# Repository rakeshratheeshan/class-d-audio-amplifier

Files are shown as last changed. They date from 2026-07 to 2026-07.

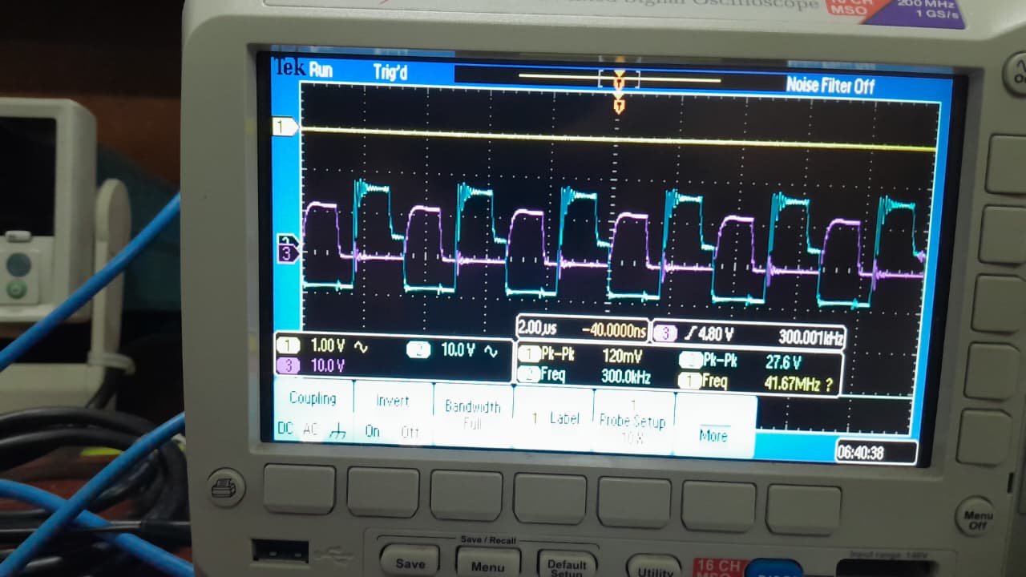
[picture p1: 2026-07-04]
Breadboard_impementation_and_Observation/Hi_Lo_gate.jpeg

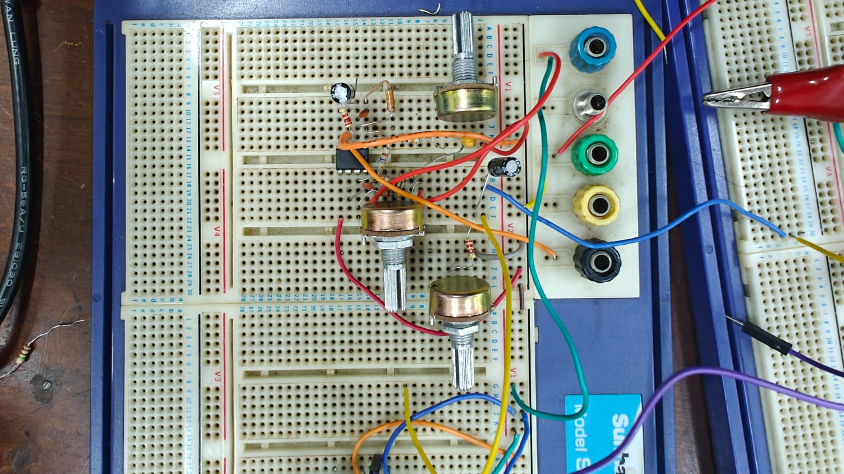
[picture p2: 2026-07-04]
Breadboard_impementation_and_Observation/pre_amp.jpeg

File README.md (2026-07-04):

# Class D Audio Amplifier

> EN 2111 — Electronic Circuit Design | University of Moratuwa  
> Department of Electronic and Telecommunication Engineering  
> Batch 23 — Group 14

A fully designed, simulated, and breadboard-implemented Class-D audio amplifier featuring a pre-amplifier with active Baxandall tone control, high-frequency PWM generation, a half-bridge MOSFET output stage with bootstrap gate driver, and a 4th-order Butterworth LC low-pass output filter.

---

## Team

| Name | Index | Task |
|---|---|---|
| De Mel D. J. | 230121D | MOSFET Gate Driver Design |
| Rahman M. F. A. | 230507R | PWM Generation Design |
| Rahul B. | 230508V | Pre-Amplifier Design |
| Ratheeshan A. R. | 230539P | Low-Pass Filter Design |

---

## System Architecture

```
Audio In → Pre-Amp → PWM Generator → Gate Driver → Half-Bridge → LC Filter → Speaker
(NE5532)   (AD8065 + LM311D)  (IR2104)     (IRF530 x2)  (4th-order Butterworth)
```

---

## Repository Structure

```
class-d-audio-amplifier/
├── report/                  # Final submitted report (PDF)
├── simulation/
│   ├── preamp/              # LTspice files — Pre-amplifier & tone control (Rahul)
│   ├── pwm/                 # LTspice files — Triangular wave gen & comparator (Abdul Rahman)
│   ├── gate-driver/         # LTspice files — IR2104 half-bridge driver (Deelaka)
│   └── filter/              # LTspice files — 4th-order LC Butterworth filter (Rakesh)
├── pcb/
│   ├── schematic/           # Altium Designer schematic files (.SchDoc, .PrjPcb)
│   └── layout/              # PCB layout files + Gerbers
└── docs/
    └── references/          # Datasheets and application notes
```

---

## Subsystem Summaries

### 1. Pre-Amplifier (`simulation/preamp/`)
- Built around the **NE5532** dual op-amp (5 nV/√Hz noise, 10 MHz BW)
- Inverting gain stage: **Av = −15 (≈ 23.5 dB)**, AC-coupled at 7.23 Hz lower cutoff
- Active **Baxandall tone control** with bass (±12 dB shelf below 200 Hz) and treble adjustment
- Volume control potentiometer for modulation index matching
- Simulated THD: **0.243%** at 500 Hz, 750 mV peak input

### 2. PWM Generation (`simulation/pwm/`)
- **Triangular wave generator**: AD8065 relaxation oscillator + inverting integrator
  - f ≈ 354 kHz (R = 3.9 kΩ, C = 330 pF, β = 0.5)
  - Integrator: Ri = 33 kΩ, Ci = 47 pF, 100 kΩ DC feedback resistor
- **Comparator**: LM311D (replaced LM393 for faster switching at 350 kHz)
- PWM duty cycle: `D(t) = 0.5 + V_audio(t) / (2 × V_tri_pk)`
- Final switching frequency reduced to **150 kHz** for IR2104 compatibility

### 3. Gate Driver (`simulation/gate-driver/`)
- **IR2104** half-bridge gate driver (final iteration)
  - Integrated dead-time generation (520 ns fixed)
  - Internal PWM inversion for complementary HS/LS outputs
  - Bootstrap capacitor: **100 nF** (Cboot > 10 × Cg = 1.8 nF)
  - VDD bypass capacitor: **1 µF** (CVDD > 10 × Cboot)
  - Bootstrap diode: **1N5819** Schottky
- MOSFETs: **IRF530** (selected over IRFZ44N for lower Qg = 26 nC and Ciss = 670 pF at 300 kHz)
- Required gate drive: Isource = 313 mA (within 83 ns, 5% of half-period)

### 4. Output Filter (`simulation/filter/`)
- **4th-order passive LC Butterworth low-pass filter** (LC ladder topology)
- Cutoff frequency: **20 kHz**, −40 dB/decade rolloff
- Designed for RS/RL mismatch (RS = 0.5 Ω, RL = 8 Ω → RL/RS ≈ 16)
- Component values: **L1 = 100 µH, C2 = 1.56 µF, L3 = 68 µH, C4 = 330 nF**
- Zobel network (future improvement): R = 5.6 Ω, C = 100 µF for variable speaker load compensation

---

## Key Design Decisions

| Decision | Chosen | Reason |
|---|---|---|
| Triangular wave IC | AD8065 (over NE555) | NE555 has DC offset and non-linear (exponential) waveform |
| Comparator | LM311D (over LM393) | Faster switching, cleaner transitions at 350 kHz |
| Gate driver | IR2104 (over LTC4444) | Integrated dead-time, simpler implementation; cost/time tradeoff |
| MOSFET | IRF530 (over IRFZ44N) | Lower Qg and Ciss → less switching loss at high frequency |
| Filter order | 4th-order (over 2nd-order) | Steeper rolloff needed after reducing fsw to 150 kHz |
| Filter type | Passive LC (over RC/active) | Zero dissipation, handles full output current, best ripple rejection |

---

## How to Contribute (For Group Members)

1. **Fork** this repository to your own GitHub account
2. **Clone** your fork locally:
   ```bash
   git clone https://github.com/<your-username>/class-d-audio-amplifier.git
   ```
3. Add the upstream remote:
   ```bash
   git remote add upstream https://github.com/230539P/class-d-audio-amplifier.git
   ```
4. Work inside **your assigned subfolder** only (see table above)
5. Push to your fork and open a **Pull Request** to `230539P/class-d-audio-amplifier`

To pull in updates from the main repo:
```bash
git fetch upstream
git merge upstream/main
```

---

## Tools Used

- **LTspice** — Circuit simulation
- **Altium Designer** — PCB schematic and layout
- **LaTeX (XeLaTeX)** — Report generation
- **Tektronix TBS1000C** — Oscilloscope measurements

---

## References

1. Texas Instruments — NE5532 Datasheet
2. Texas Instruments — LM311 Datasheet
3. Analog Devices — AD8065 Datasheet
4. Infineon — IRF530N Datasheet
5. Infineon — IR2104 Datasheet
6. Analog Devices — AN-1070: Class D Audio Amplifier Basics
7. Texas Instruments — Class-D Audio Amplifier Design Basics (SLAA701A)
8. Chris Bowick — *RF Circuit Design*, Reed Elsevier, 1982

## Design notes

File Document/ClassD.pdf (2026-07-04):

## University of Moratuwa

### Department of Electronic and Telecommunication Engineering

Faculty of Engineering

# Class D Audio Amplifier

### Design, Simulation and Practical Implementation

### Module: EN 2111 - Electronic Circuit Design

Batch: 23 | - | Group: 14

### Group Members

Name | | Index Number
De Mel D. J. | | 230121D
Rahman M. F. A. 230507R
Rahul B. | | pakaya
Ratheeshan A. R. 230539P

### June 26, 2026

# Contents

1 Introduction | 1
2 Theoretical Background | 2
3 Conclusion | 22
Datasheets and References | 23

i

# Introduction

## 1.1 Background and Motivation

Class-D amplifiers are widely used in modern audio systems because of their high efficiency. Unlike conventional linear amplifiers, they amplify audio by converting it into a high-frequency Pulse Width Modulated (PWM) signal, allowing the output MOSFETs

to operate as switches. This greatly reduces power loss while maintaining good audio quality. The aim of this project was to design, simulate, and implement a Class-D audio amplifier using commonly available components. Several design iterations were carried out to improve the PWM generation, gate driving, and output filtering stages before achieving the final design.

## 1.2 Objectives

The objectives of this project are to:

- Design and implement a complete Class-D audio amplifier.
- Generate PWM using a high-frequency triangular carrier and comparator.
- Design the MOSFET gate driver and output stage.
- Recover the amplified audio signal using an LC low-pass filter.
- Verify the design through simulation and practical testing.

## 1.3 Scope of the Report

This report covers the design, simulation, implementation, and testing of the Class-D audio amplifier, including the pre-amplifier, PWM generator, gate driver, output stage, LC filter, and PCB design.

## 1.4 Report Organisation

Chapter 2 presents the design and theory of each subsystem, while the remaining chapters cover simulation, implementation, testing, PCB design, results, challenges, and the final conclusions.

# Theoretical Background

## 2.1 Pre-Amplifier

### 2.1.1 Purpose and Role in the Signal Chain

The pre-amplifier stage serves as the front-end interface between audio sources such as smartphones, media players or DACs and the PWM stage of the Class-D Amplifier. The standard line-level audio equipment delivers audio signals ranging from 200 millivolts to 1 volts. The comparator LM311D requires an audio signal which should closely match the amplitude of the triangular wave to create a good PWM with high modulation index. For this purpose a pre-amplifier is needed. By maximizing the modulation index, the SNR increases and the voltage utilization factor of the output power rails also increases.

Beyond this, The pre-amplifier stage fullfills these roles:

- Impedance Buffering: Presenting a high input impedance to the incoming source

to eliminate signal loading, ensuring flat frequency transmission from the playback device.

- DC Isolation and Biasing: Utilizing an AC-coupling network to strip away any

residual DC offsets from the input source, ensuring that the audio signal centers precisely around the analog ground (0 V) of the split-supply system.

### 2.1.2 Design Considerations and Circuit Analysis

The complete pre-amplifier is designed around the NE5532 dual operational amplifier which has 5 nV/

√
Hz noise density and 10 MHz small-signal bandwidth which makes it perfect for our application.

### 1. Input Gain Stage

The first stage (U1) is configured as an inverting amplifier.The mid-band voltage gain (Av1):

Av1 = −

R2
R1

= −

33 kΩ
2.2 kΩ = −15 (≈ 23.5 dB) | (2.1)

The lower −3 dB cut-off frequency (fL1) of this initial block:

fL1 =

1
2πR1C1

=

1
2π × 2.2 kΩ × 10 µF
≈ 7.23 Hz | (2.2)

CHAPTER 2. THEORETICAL BACKGROUND | EN 2111 — Class D Amplifier

This pole is placed below the nominal 20 Hz audible threshold to avoid phase shifts in the bass range. Noise suppression is managed by the feedback capacitor C2 in parallel with R2 forming a low-pass filter with a corner frequency (fH1):

fH1 =

1
2πR2C2

=

1
2π × 33 kΩ × 47 pF
≈ 102.6 kHz | (2.3)

### 2. Active Baxandall Tone Control Stage

The output of U1 feeds into an active Baxandall tone control network built around the second operational amplifier stage (U3).

- Bass Control Loop: Resistors R3, R6, and capacitor C3 (47 nF) function together

with the BASS linear potentiometer (R4 + R5 = 100 kΩ). At low frequencies, C3

behaves as an open circuit, allowing the position of the wiper to adjust the relative feedback resistance ratio, boosting or cutting low frequencies. At high frequencies, C3 shorts out the potentiometer, rendering the bass control inactive.

- Treble Control Loop: Resistors R7, R8, R11, and capacitor C4 (2.2 nF) form the

treble adjustment route across the TREBLE potentiometer (R9 + R10 = 50 kΩ).

Because C4 features low impedance at high frequencies, it allows the treble potentiometer to modify the high-frequency feedback path, controlling high-frequency shelving adjustments without affecting the lower audio register.

### 3. Volume Control and Output Coupling

The output of the tone equalizer stage (U3) passes through a isolation resistor R12 = 1 kΩ to a variable passive potential divider labeled VOLUME (R13 = 1 kΩ, R14 = 45 kΩ). This

potentiometer scales the processed signal down to the ideal peak matching envelope of the triangular wave to generate PWM signal with maximum modulation index. Finally, an impedance-matching resistor R15 = 2.2 kΩ and an output AC-coupling capacitor C5 = 10 µF strip away any accumulated operational amplifier DC offsets before routing the clean baseband audio into the LM311D PWM comparator.

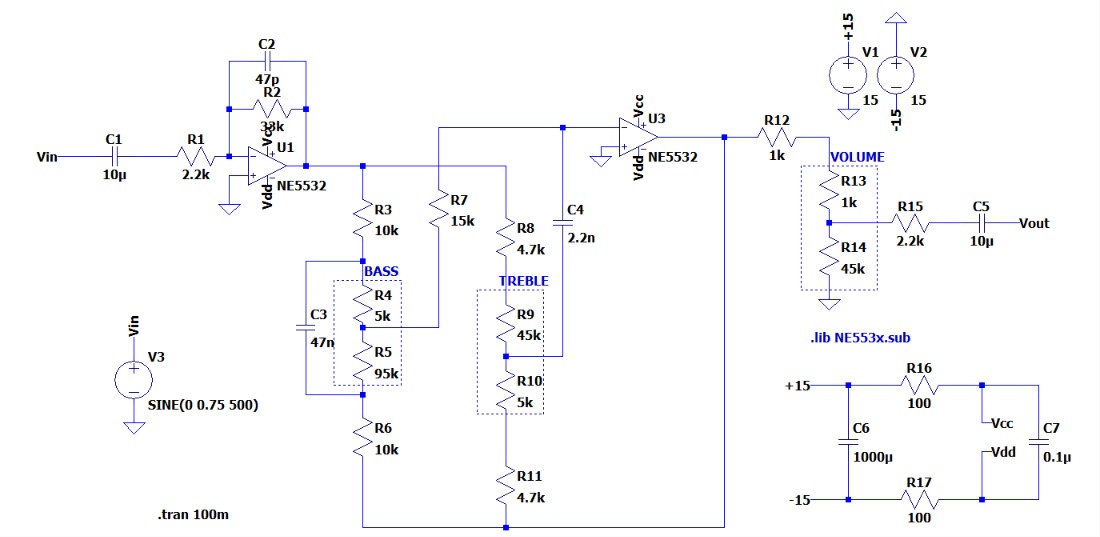
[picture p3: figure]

Figure 2.1: Pre-Amplifier Circuit on LTSpice

### 2.1.3 Pre-Amplifier Simulation

The Pre amplifier circuit simulated in LTSpice.

### 1. AC Small-Signal Sweep (Bode Analysis)

To evaluate the control envelope of the active Baxandall network, an AC small-signal sweep was simulated from 1 Hz to 100 kHz with a 1 V reference AC excitation input. The potentiometer components were modeled under variable resistance ratios to inspect the system response across distinct user settings:

- Flat Audio Passband: With both the BASS (R4, R5) and TREBLE (R9, R10)

potentiometer networks configured to their nominal midpoints, the circuit demonstrates a highly linear, flat magnitude transmission profile across the audible core range.

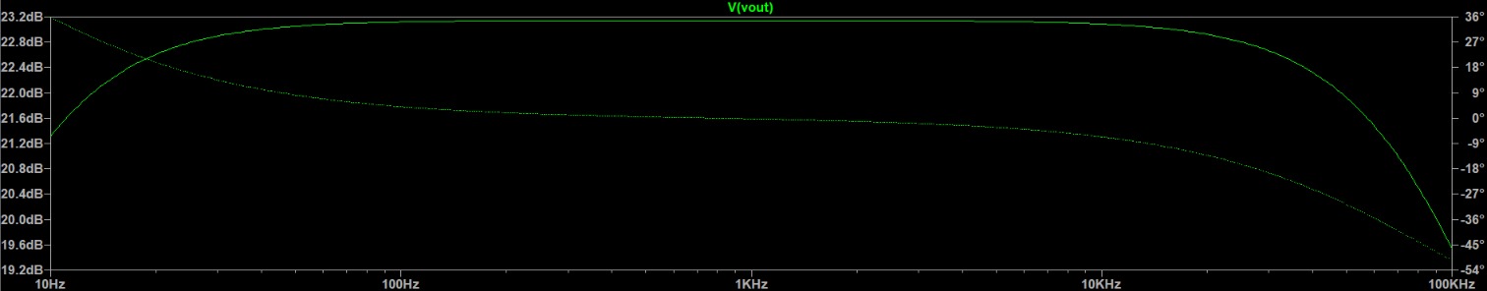
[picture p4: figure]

Figure 2.2: Flat Response

- Low-Frequency Adjustment (Bass Boost/Cut): Adjusting the BASS poten-

tiometer wiper sweeps the low-frequency shelf characteristic below 200 Hz. At maximum boost configuration, an approximate +12 dB shelf gain enhancement is observed near the lower frequencies, whereas max cut introduces corresponding low-end attenuation without distorting mid-range frequencies.

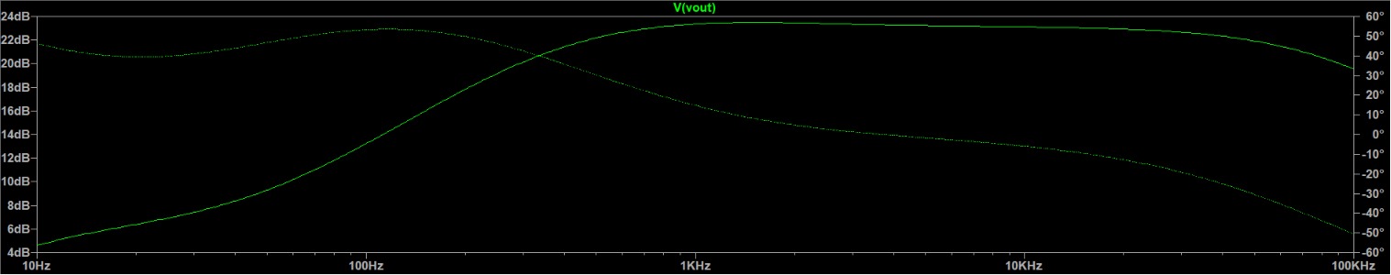
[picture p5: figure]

Figure 2.3: Bass Boost

### 2. Total Harmonic Distortion (THD) Analysis

Because the processed audio signal directly governs the pulse-width generation thresholds inside the downstream LM311D comparator, maintaining minimal harmonic coloration is vital. A high-resolution discrete Fourier Transform (DFT) analysis was performed

using a 500 Hz sinusoidal test tone with a representative input amplitude of 750 mVpeak as modeled by source V3.

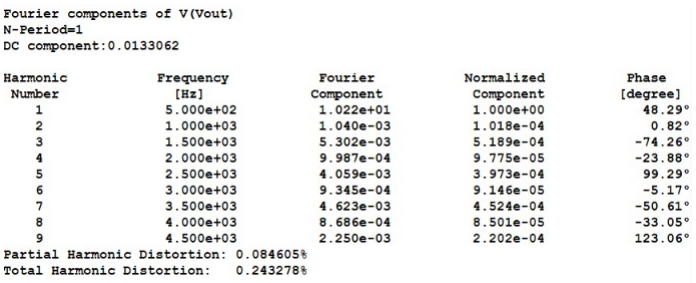
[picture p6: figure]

Figure 2.4: Total Harmonic Distortion Analysis

The calculated THD value falls well within ideal parameters. This exceptionally low distortion value confirms that the NE5532 operational amplifiers preserve fundamental signal composition with zero clipping or crossover limitations before the audio signal enters the high-speed PWM conversion stage.

## 2.2 PWM Generation

The Class D amplifier uses pulse width modulation to convert the analog audio signal into a high-frequency switching waveform. In this method, the audio signal is compared with a high-frequency triangular carrier. The output of the comparator becomes a PWM signal whose duty cycle changes according to the instantaneous amplitude of the audio signal. This PWM signal is then sent to the gate driver and MOSFET output stage.

### 2.2.1 Triangular Wave Generator

The triangular wave generator provides the carrier signal for PWM generation. Since the audio input is limited to approximately 20 Hz–20 kHz, the carrier frequency must be significantly higher. A target frequency of approximately 350 kHz was selected. Initially, an NE555 timer-based circuit was designed and tested, using an RC network to produce an approximate triangular waveform. This approach was chosen due to the simplicity, low cost, and ease of configuration of the NE555 as an oscillator.

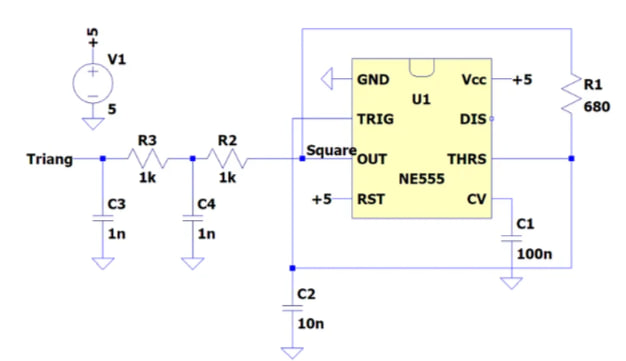
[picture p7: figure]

Figure 2.5: Initial NE555-based triangular wave generation circuit

The NE555-based design produced a triangular waveform with a significant DC offset because its output switches between 0 V and VCC, resulting in a carrier centred above 0 V . This shifted the comparator threshold and caused incorrect PWM duty cycles even when the audio input was zero. In addition, the RC charging and discharging process is exponential rather than linear, leading to a non-ideal triangular waveform and potential distortion. Due to these limitations, the design was replaced with a high-speed AD8065 op-amp implementation.

The final design uses two AD8065 stages: a relaxation oscillator (Schmitt trigger) to

generate a square wave, followed by an inverting integrator that converts the square wave into a stable, low-distortion triangular waveform suitable for PWM generation.

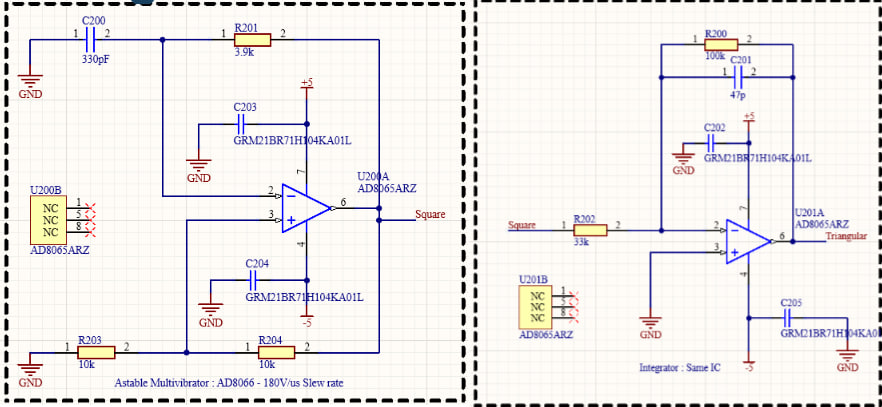
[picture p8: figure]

Figure 2.6: Final AD8065-based triangular wave generator using oscillator and integrator stages

The final triangular wave generator was implemented using the AD8065 high-speed op-amp, selected for its high bandwidth and slew rate, which are necessary for operation at the target carrier frequency of approximately 350, kHz. The circuit consists of a relaxation oscillator that generates a square wave and an inverting integrator that converts the square wave into a triangular waveform.

The oscillator frequency is given by

f =

1
2RC ln
1+β
1−β
| (2.4)

where β =

Rlower
Rupper+Rlower

. Using R = 3.9, kΩ, C = 330, pF, and equal feedback resistors of 10, kΩ (β = 0.5), the calculated oscillation frequency is approximately 354, kHz, which

closely matches the design target.

The square wave output is applied to an inverting integrator with Ri = 33, kΩ and Ci = 47, pF. The integrator produces a triangular waveform whose amplitude depends on the carrier frequency and the integrator time constant. A 100, kΩ resistor was connected in parallel with the integrator capacitor to provide a DC feedback path and prevent output saturation caused by op-amp offset voltages and bias currents.

The measured waveform closely followed the simulated result, although some noise and distortion were observed. These effects are mainly attributed to parasitic capacitances, supply noise, PCB layout limitations, square-wave feedthrough, and oscilloscope probe loading. Despite these non-idealities, the circuit produced a stable triangular carrier suitable for PWM generation in the Class-D amplifier.

### 2.2.2 Comparator Stage

The comparator stage generates the PWM signal by comparing the amplified audio signal with the high-frequency triangular carrier. When the audio signal is greater than the carrier, the comparator output is HIGH; otherwise, it is LOW. As the audio amplitude varies, the duty cycle of the output changes proportionally, producing the PWM waveform required for Class-D amplification.

For a symmetric triangular carrier, the PWM duty cycle can be approximated by

D(t) = 1
2

+

Vaudio(t)

2Vtri,pk

(2.5)

To maintain linear PWM operation, the audio signal amplitude must remain smaller than the carrier amplitude. If the audio signal exceeds the carrier amplitude, overmodulation occurs, resulting in clipping and increased distortion.

During the mid-evaluation stage, PWM generation was implemented using the LM393 comparator. Although it successfully demonstrated PWM operation, its open-collector output required a pull-up resistor, resulting in slower rise times and reduced switching performance at high carrier frequencies.

For the final design, the LM393 was replaced with the LM311D comparator, which offers faster switching characteristics and cleaner output transitions. This change improved PWM signal quality and reduced timing errors at the selected carrier frequency of approximately 350, kHz.

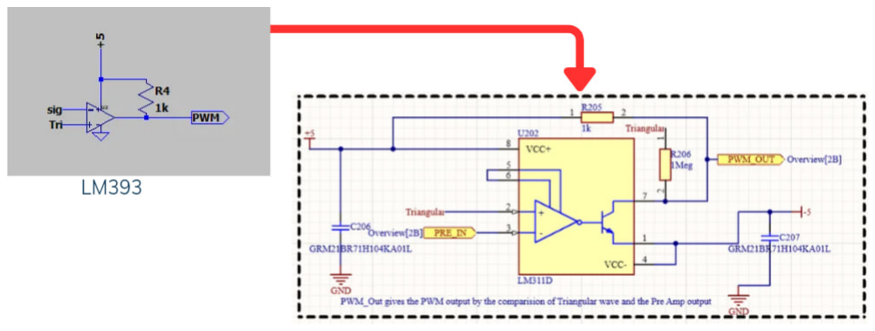
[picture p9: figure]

Figure 2.7: Transition from the LM393-based PWM generator used during mid-evaluation to the final LM311D-based high-frequency PWM generation circuit

In the final implementation, the audio signal from the pre-amplifier and tone control stage is applied to one input of the LM311D, while the triangular carrier generated by the AD8065 oscillator-integrator circuit is applied to the other. The resulting PWM output is then fed to the MOSFET gate driver stage.

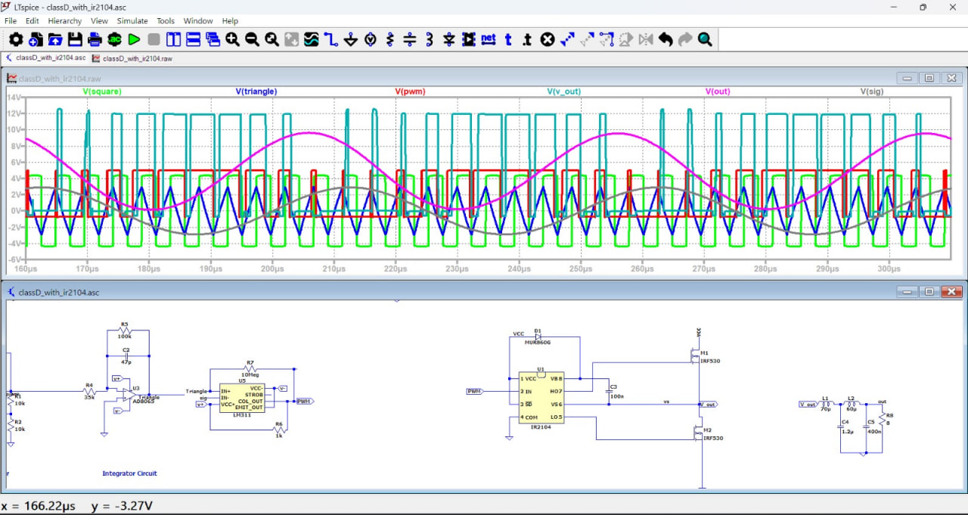
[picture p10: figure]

Figure 2.8: Simulation of PWM generation using the LM311D comparator

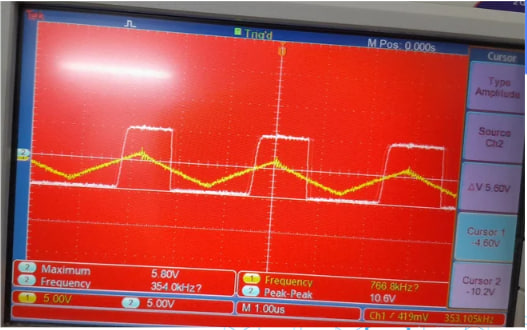
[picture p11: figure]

Figure 2.9: Measured high-frequency PWM output waveform generated using the LM311D comparator

The measured PWM waveform closely matched the simulation results. Minor variations were observed due to noise, PCB parasitics, and supply fluctuations. Since the PWM signal directly controls the MOSFET switching stage, proper decoupling, grounding, and carrier waveform quality are important to minimize jitter and distortion.

### 2.2.3 PWM Frequency Selection

The PWM switching frequency was set to approximately 350 kHz, much higher than the audio band (∼ 20 kHz), allowing effective filtering of switching components while preserving the audio signal. The ratio fs/faudio,max ≈ 17.5 provides adequate separation

for proper reconstruction.

Although higher switching frequency improves filtering and reduces ripple, it increases switching losses and driver demands. Therefore, 350 kHz was chosen as a practical tradeoff between efficiency, signal quality, and hardware limitations, and is compatible with the overall system design.

## 2.3 MOSFET Gate Driver and Output Stage

### 2.3.1 MOSFET Selection Criteria

Candidates for mosfets found locally in Sri Lanka:

- IRF530
- IRFZ44N

Table 2.1: MOSFET Comparison: IRFZ44N vs IRF530 for Half-Bridge Output Stage

Parameter | IRFZ44N | IRF530
VDS (max) | 55 V | 100 V
ID (max, TC = 25◦C) | 49 A | 14 A
RDS(on) (max) | 17.5 mΩ | 160 mΩ
Qg (total gate charge) | 63 nC | 26 nC
Ciss (input capacitance) | 1470 pF | 670 pF
tr (rise time) | 60 ns | 34 ns
tf (fall time) | 45 ns | 24 ns
VGS(th) (threshold) | 2–4 V | 2–4 V
PD (max dissipation) | 94W | 74W

300 kHz Performance Higher conduction efficiency Lower switching loss

At 300 kHz, gate charge and capacitance dominate switching performance. IRF530 has lower Qg and Ciss, giving lower switching loss and better high-frequency operation. IRFZ44N has lower RDS(on) but higher gate-drive loss. Hence, IRF530 was selected for the final design.

∴ Mosfet used for the half bridge output stage → IRF530.

Calculating source and sink current required to turn on mosfets

Source current:

Isource =

Qg
tr

(2.6)

Sink current:

Isink =

Qg
tf

(2.7)

T =

1
300kHz | (2.8)

At a switching frequency of 300 kHz, the switching period is 3.33 µs, corresponding to a half-period of 1.67 µs. A common design guideline is to complete the MOSFET switching transition within 5% of the half-period, corresponding to approximately 83 ns. This

minimizes switching losses and distortion while maintaining efficient operation at high switching frequencies.

tr, tf < 0.05 ×

T
2
= 83ns | (2.9)

Isource =

26nC
867mA = 313mA | (2.10)

### 2.3.2 Gate Driver

Amplification of the Audio signal occurs at the Half bridge output stage. The half-bridge power stage consists of two power MOSFETs (high-side and low-side) connected in series

across the supply rails, with the output taken from their common node. To prevent simultaneous conduction of both devices (a condition known as shoot-through, which causes a low-impedance short circuit across the supply and can destroy the MOSFETs),

a short delay – the dead time – is inserted between the turn-off of one device and the turn-on of the other.

Considerations when designing the gate driver:

- Frequency of Triangular wave → 300kHz
- Comparator output → 0V − 5V
- Supply voltage to the half bridge output stage → 15V .
- Gate charge of IRF530 → 26nC

Gate driver requirements:

- Should be able to handle a switching frequency of 300kHz
- Should source and sink
- The input should be able to handle −3V → 6V addressing voltage spikes induced

by parasitic inductance and capacitance.

The gate driver should be able to drive the high and low side Mosfets with two complementary PWM signals inverted with respect to each other. A bootstrap circuit should be implemented to drive the High side mosfet.

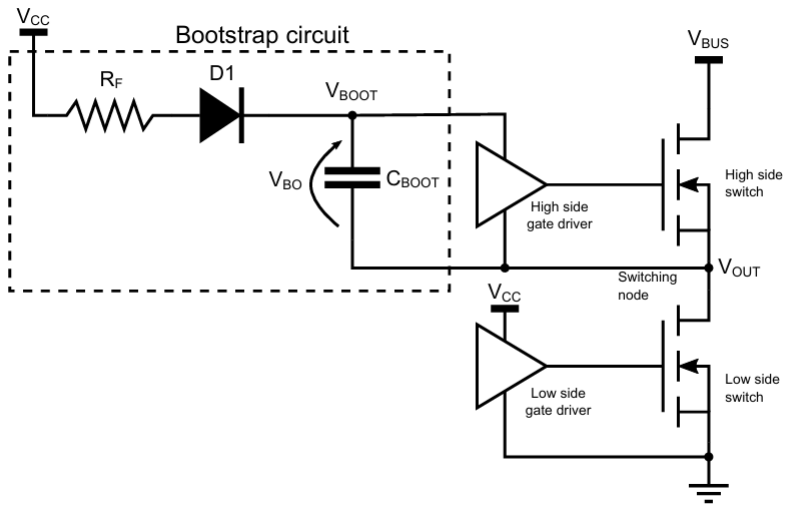
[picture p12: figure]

Figure 2.10: Bootstrap circuit

Calculation of bootstrap capacitor value

The bootstrap capacitor should be sized to have enough energy to drive the gate of the high-side MOSFET without being depleted by more than 10.This bootstrap cap should be at least 10 times greater than the gate capacitance of the high-side FET.

Cg =

Qg

VDD − VBoot Diode

(2.11)

Where Qg is the gate capacitance of the Mosfet (IRF530) used.

Cg =

26nC
15 − 0.6
Cg = 1.8nF | (2.12)
Cboot > 10Cg | (2.13)

Cboot was chosen to be 100nF.

The charge to replenish the bootstrap capacitor must come from some larger bypass capacitor, usually the VDD bypass capacitor. As a rule of thumb, this bypass capacitor should be sized to be at least 10 times larger than the bootstrap capacitor so that it is not completely drained during the charging time of the bootstrap capacitor. This allows the bootstrap capacitor to be properly resplenished during the charging sequence.

CV DD > 10Cboot | (2.14)

CV DD was chosen to be 1uF.

A Schottky diode (1N5819) was used as the external bootstrap diode.

We went through 3 iterations for the design of the Gate driver.

Iteration 1

Implemented using a Low side gate driver UCC27517. Implemented an external Bootstrap circuit.

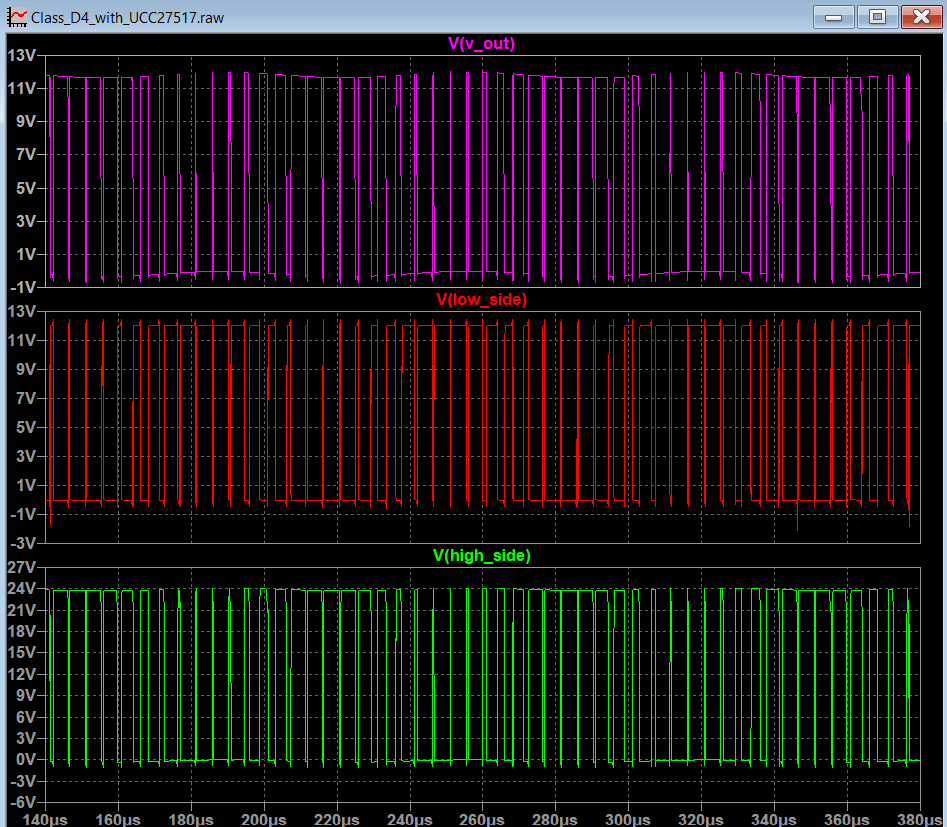
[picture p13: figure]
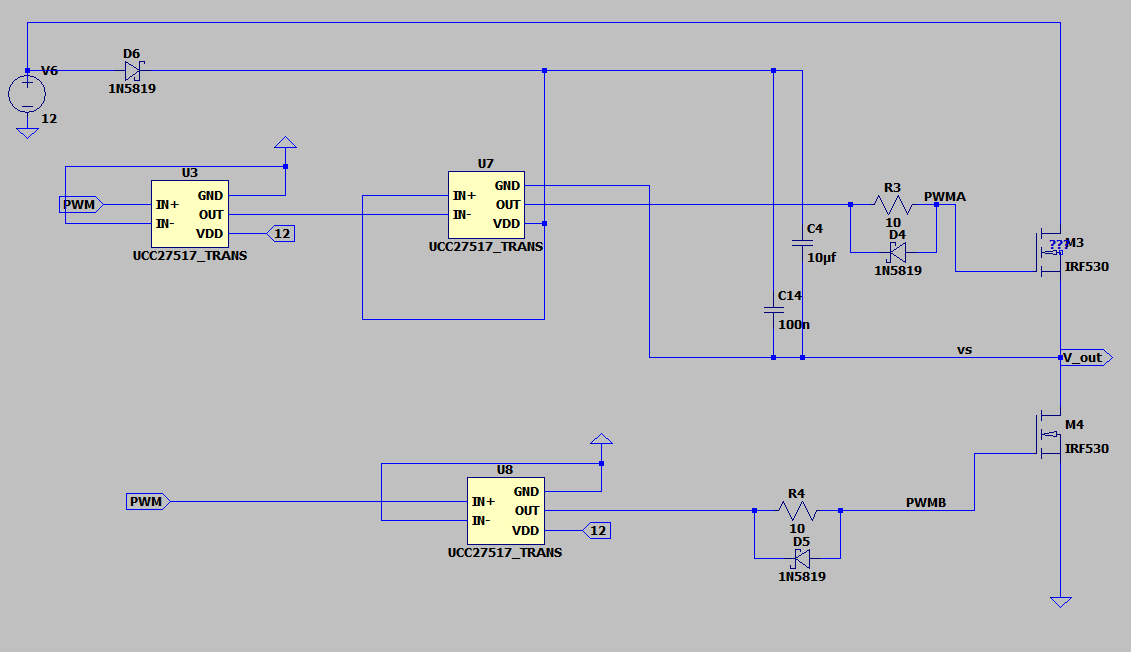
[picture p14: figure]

(a) Iteration 1 | (b) Simulation results of iteration 1

Figure 2.11: Iteration 1 circuit and corresponding simulation results

The problem with this circuit was implementing deadtime. Since the duty cycle varies, a simple RC - delay circuit with a fixed delay would not suffice. Adding an asymmetric gate drive network with a diode and resistor also proved futile when implemented on the breadboard. A high current was drawn due to cross conduction.

Iteration 2

Implemented using the LTC4444 high frequency high voltage gate drive. Adaptive shoot-through protection prevents both MOSFETs from conducting simultaneously. The UCC27517 was used as an inverter and pulse shaper to provide clean inputs to the LTC4444.

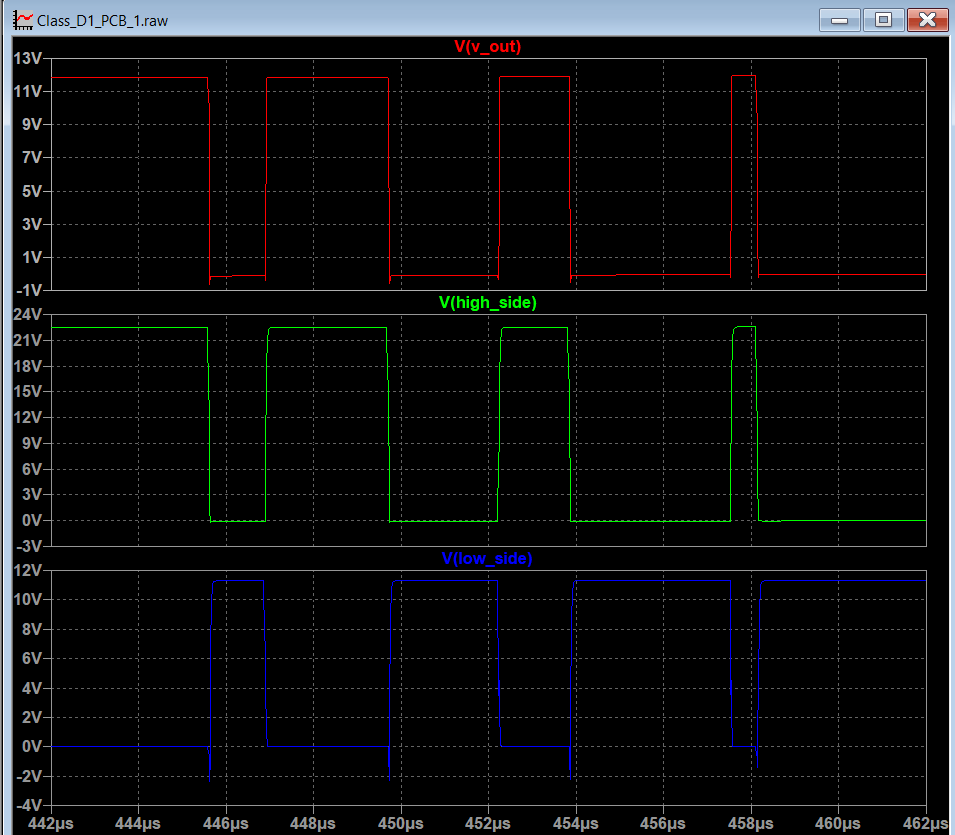
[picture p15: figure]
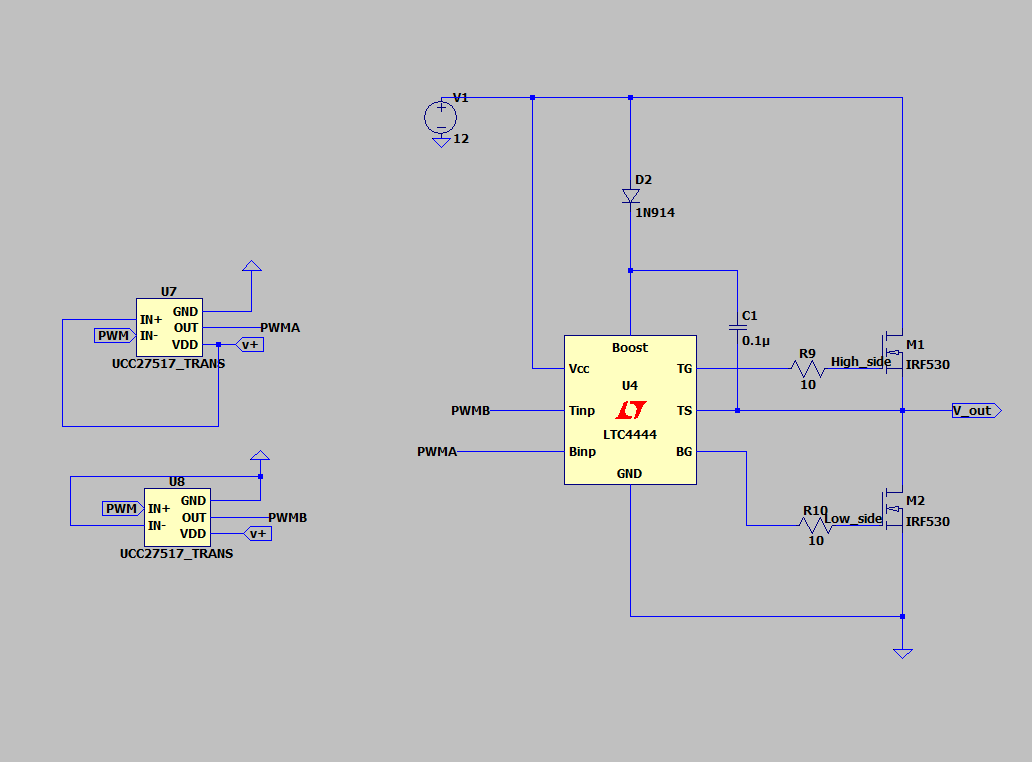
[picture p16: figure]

(a) Iteration 1 | (b) Simulation results of iteration 1

Figure 2.12: Iteration 2 circuit and corresponding simulation results

We planned to implement this circuit on a PCB. After cost and time considerations we moved onto to the third and final iteration.

Iteration 3

Used the IR2104, which implements dead time and internally inverts the pwm signal and produces separate outputs for the High side and Low side Mosfets.

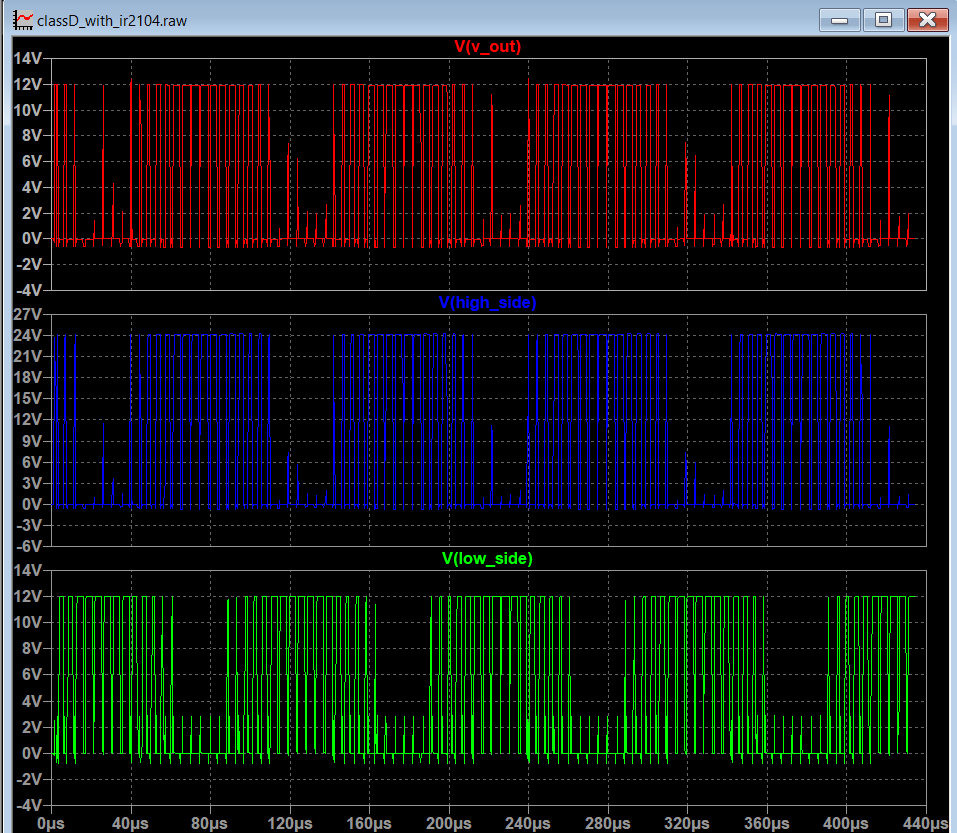
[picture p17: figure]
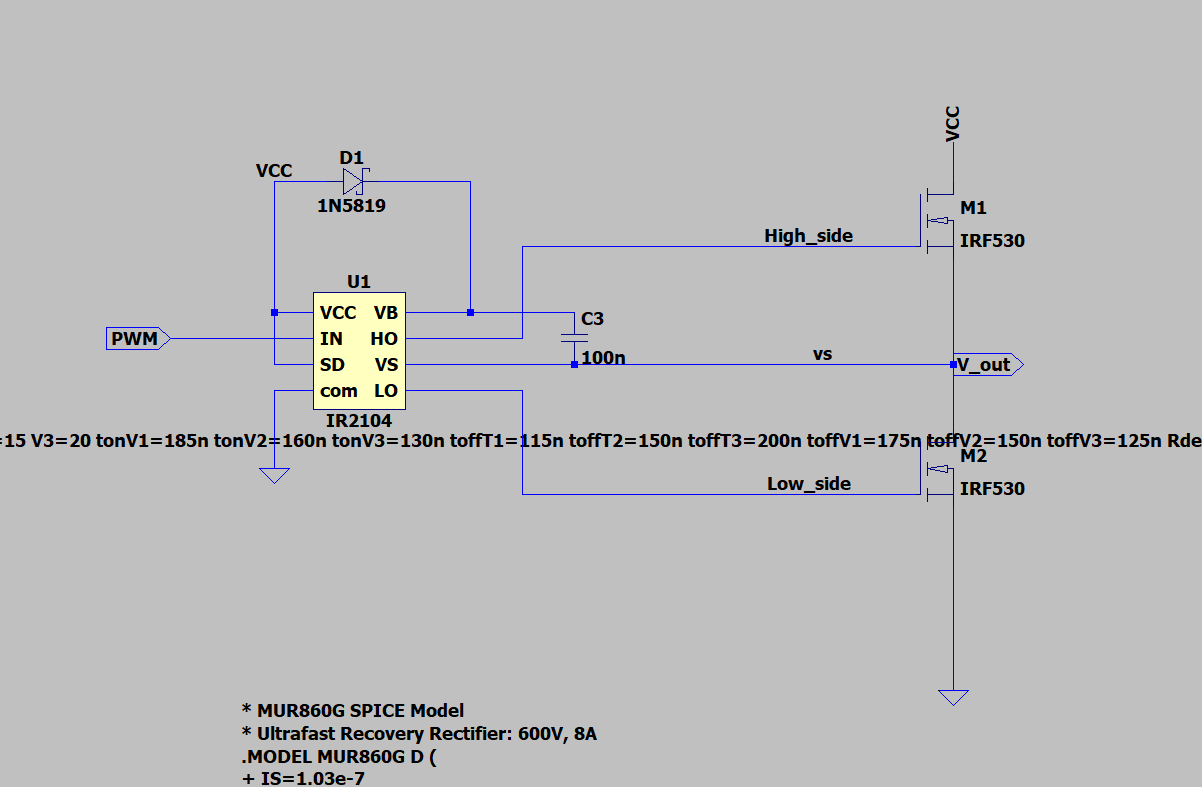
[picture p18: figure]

(a) Iteration 3 | (b) Simulation results of iteration 3

Figure 2.13: Iteration 2 circuit and corresponding simulation results

Using the IR2104 led us to decrease the triangular wave frequency to 150kHz.

Table 2.2: Gate Driver Comparison: LTC4444 vs IR2104 for Half-Bridge Stage

Parameter | LTC4444 | IR2104
Supply Voltage VCC | 7.2–13.5 V | 10–20 V
Output Configuration | Bootstrap | Bootstrap
Bootstrap Voltage (max) | 114 V | 600 V offset
Peak Source Current | 2.5 A (TG), 3 A (BG) | 130 mA
Peak Sink Current | 1.2 Ω TG, 0.55 Ω BG pull-down | 270 mA
Rise Time (tr) | 8 ns (TG), 6 ns (BG) | 680 ns*
Fall Time (tf ) | 5 ns (TG), 3 ns (BG) | 150 ns*
Propagation Delay (HS) | 25 ns | 680 ns
Propagation Delay (LS) | 19 ns | 150 ns
Dead Time | Adaptive shoot-through protection | 520 ns fixed
Input Logic | Independent HS/LS inputs | PWM + SD pin
Shoot-through Protection | Adaptive | Built-in
Suitability at 300 kHz | Excellent | Acceptable

The LTC4444 provides substantially higher gate-drive current, lower propagation delay, and significantly faster switching transitions than the IR2104. These characteristics make it highly suitable for high-frequency operation around 300 kHz. The IR2104 offers a simpler implementation with integrated dead-time generation and shoot-through protection, but its larger propagation delays reduce timing accuracy and duty-cycle range at high switching frequencies.

## 2.4 Filter

### 2.4.1 Filter Type selection

Table 2.3: Output Filter Type Selection for Class D Amplifier

Parameter | Active Filter | Passive RC | Passive LC
Power Dissipation | Low | High (due to R) | Near-zero (lossless
| | | L, C)
Efficiency at Full Power | Poor (op-amp rails
| needed) | Very poor | Excellent
Output Impedance | Low (op-amp
| driven) | = R (loads signal) | Very low in
| | | passband
Rolloff (2nd order) | −20 dB/decade | −20 dB/decade | −20 dB/decade
Noise Added | Yes (op-amp noise
| floor) | Thermal noise in R | Near zero
Supply Rails Required | Yes | No | No
Component Count | High | Low | Moderate
PWM Switching Ripple Rejection | Moderate | Poor (limited
| | rolloff) | Excellent
Suitable for >1W Output | No | No | Yes
Failure Risk | Op-amp breakdown,
| latch-up | Thermal failure of R | None (no active
| | | devices)
Verdict | Not suitable | Not suitable | Correct choice

An active filter cannot survive the rail-to-rail PWM voltage swing at the half-bridge output (12 V, 50 V, or higher depending on supply), as no practical op-amp operates under these conditions. A passive RC filter, while structurally simpler, dissipates substantial power in the series resistor whenever output current flows, making it thermally and efficiency-wise impractical at any meaningful power level. The passive LC filter is the only viable option: inductors and capacitors are ideally lossless, present near-zero impedance in the passband, carry the full output current without dissipation, and provide the steep rolloff required to suppress switchingfrequency harmonics while passing the audio band unattenuated.

### 2.4.2 Cut-off Frequency and Component Selection

In order to obtain constant gain accross all the frequencies ranging 20Hz to 20kHz we chose butterworth 2nd order filter initially. Since it has a maximally flat passband. Initially the Pwm frequency was 350khz however due to the limitations of implementing it on the breadboard we lowered the pwm frequency to 150Khz. Hence we needed much steeper rolloff, So we chose 4th order LC butterworth filter.
Following is the Calculations done for component selection.

Note on RS mismatch:

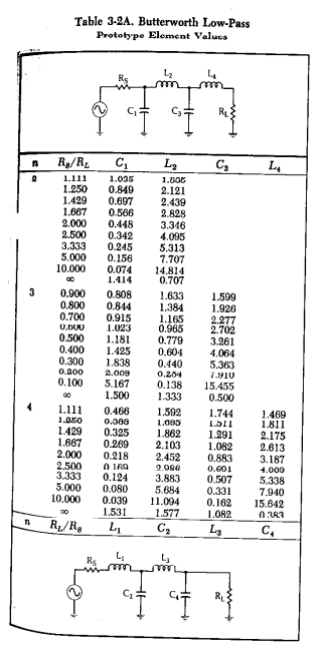
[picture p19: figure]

Since RS = 0.5 Ω in the MOSFETs ,not equal to RL = 8Ω source/load case.

Cutoff Frequency: 20Khz
Amax : max passband ripple: 3db

Source/Load Ratio (Unmatched RS, RL) and prototype values from the ta-

ble
RL
RS

≈

8
0.5

≈ 16

L1 = 1.531, | C2 = 1.577
L3 = 1.082, | C4 = 0.383

Frequency Scaling Factor

kf =

2πfC
√

10 Aworst/10 − 1

kf = 2πfC

kf = 2π × fC = 125,663.706 rad/s

Impedance Scaling Factor

km =

RL
1

= 8 Ω

Component Scaling Equations

C

′ =

C
kmkf

L

′ =

km
kf

L

Scaled Component Values

C

′
1 =

C1
kmkf

= 1.56 µF

C

′
2 =

C2
kmkf

= 380 nF

L

′
1 =

km
kf

L1 = 97.46 µH

L

′
2 =

km
kf

L2 = 68.82 µH

Figure 2.14: Butterworth Low-Pass Prototype Element Values and corresponding LC ladder topology, used as the basis for the unscaled C1, C2, L1, L2 values above.

Practicle component value

C

′

2 = 1.56 µF, C′

4 = 330 nF, L′

1 = 100 µH, L′
3 = 68 µH.

### 2.4.3 Filter Response and THD Considerations

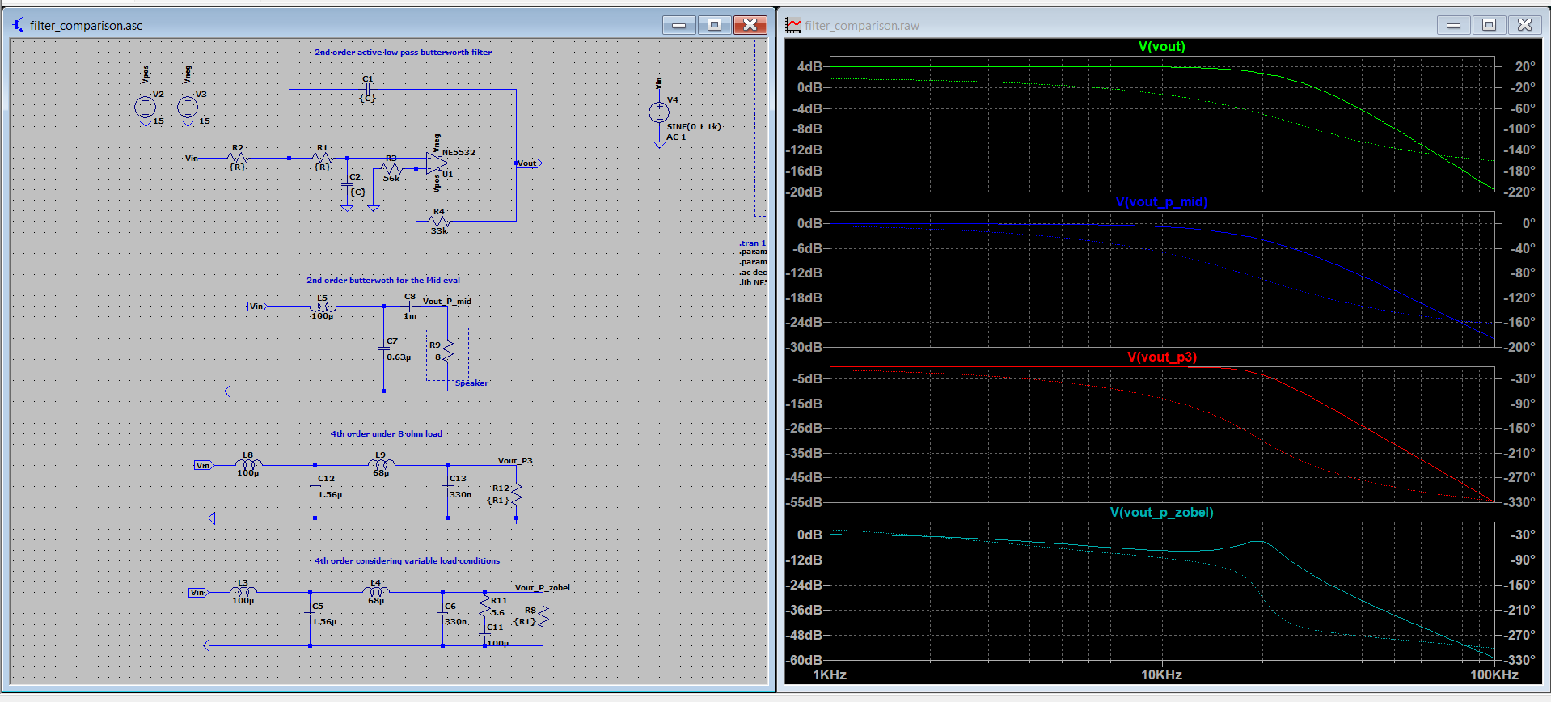
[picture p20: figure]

Thecorresponding AC sweep (1 kHz–100 kHz) magnitude and phase Bode plots for each

configuration are shown on the right, illustrating the rolloff and phase behavior differences introduced by load variation and filter order.

LTspice comparison of output filter topologies for the Class D inverter stage:

- (top) 2nd-order active low-pass Butterworth filter (NE5532-based) used as the ideal

magnitude/phase reference;

- (upper-middle) 2nd-order passive Butterworth LC filter with 8 Ω load, designed for

the mid, a rolloff of 20db can be seen;

- (lower-middle) 4th-order passive LC ladder filter under fixed 8 Ω load This was the

design implemented on the final Evaluation has a -3db cutoff at 20Khz and a rolloff of -40db;

- (bottom) 4th-order filter re evaluated under variable/Zobel compensated load con-

ditions.This was designed as a future improvement. The reason being the connected speaker is not purely resistive it has inductance and the actual impedance varies with the frequency therefore a zebel network with R = 5.6 Ω and C = 100uF is added to stabilize the filter response across variable loads.

## 2.5 Simulation Results

### 2.5.1 End-to-End System Simulation

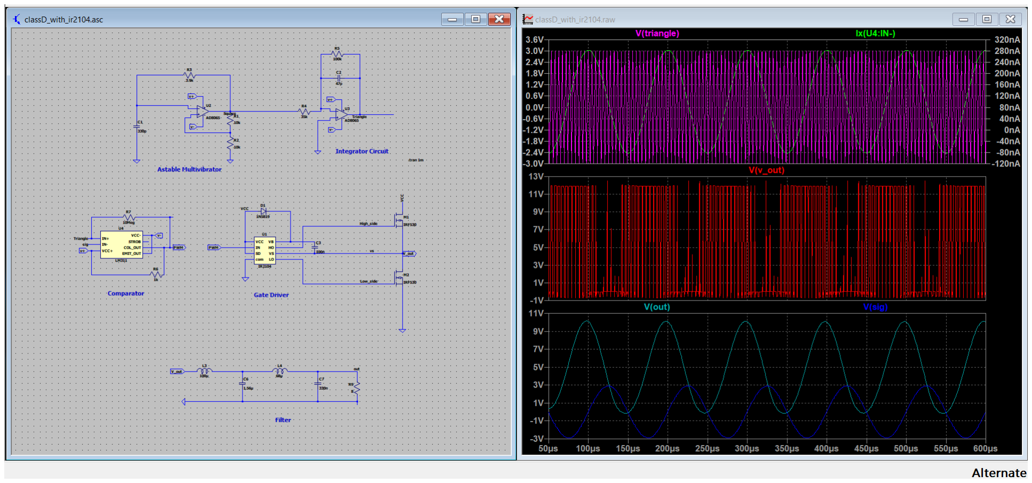
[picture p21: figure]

- The fist plot Shows Triangular wave and the input audio signal which are compared

to generate the logic level PWM.

- The second plot shows the PWM output from the gate driver created from the logic

pwm from the comparator. This output is used to drive the load. Which varies between 0 and 12V.

- This plot shows the amplified audio signal given to the speaker (green) and the

input audio(blue). Which clearly shows the signal has been amplified. The out-

put waveform is obtained after the PWM wave is passed through the Filter which removes high frequencies and gives a smooth sine wave.

## 2.6 Breadboard Implementation

(a) Triangular wave & comparator | (b) Pre amplifier

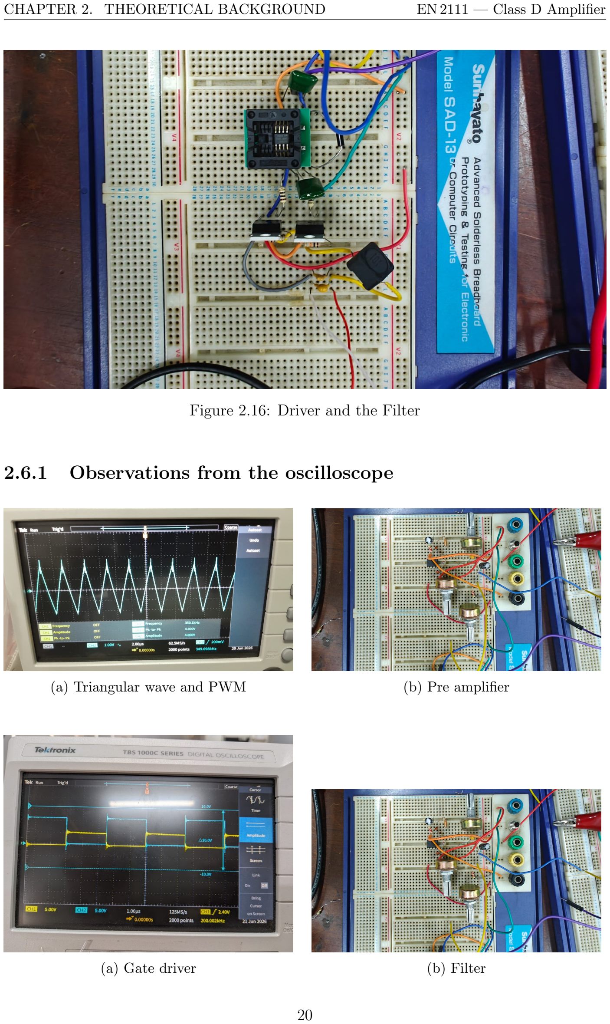
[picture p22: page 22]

Figure 2.16: Driver and the Filter

### 2.6.1 Observations from the oscilloscope

(a) Triangular wave and PWM | (b) Pre amplifier
(a) Gate driver | (b) Filter

## 2.7 PCB Design

Here we have included the designed PCB. This was done due to the limitations of implementing high frequencies on the breadboard. However we couldn’t manufacture the PCB for the final evaluation.

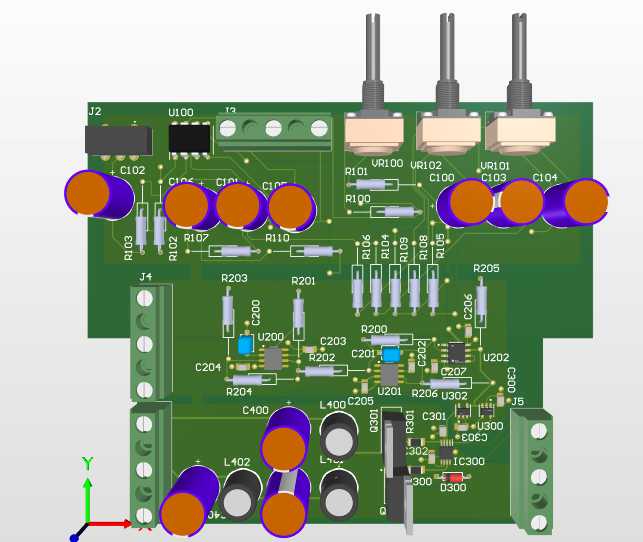
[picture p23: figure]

Figure 2.19: PCB

### 2.7.1 Schematic

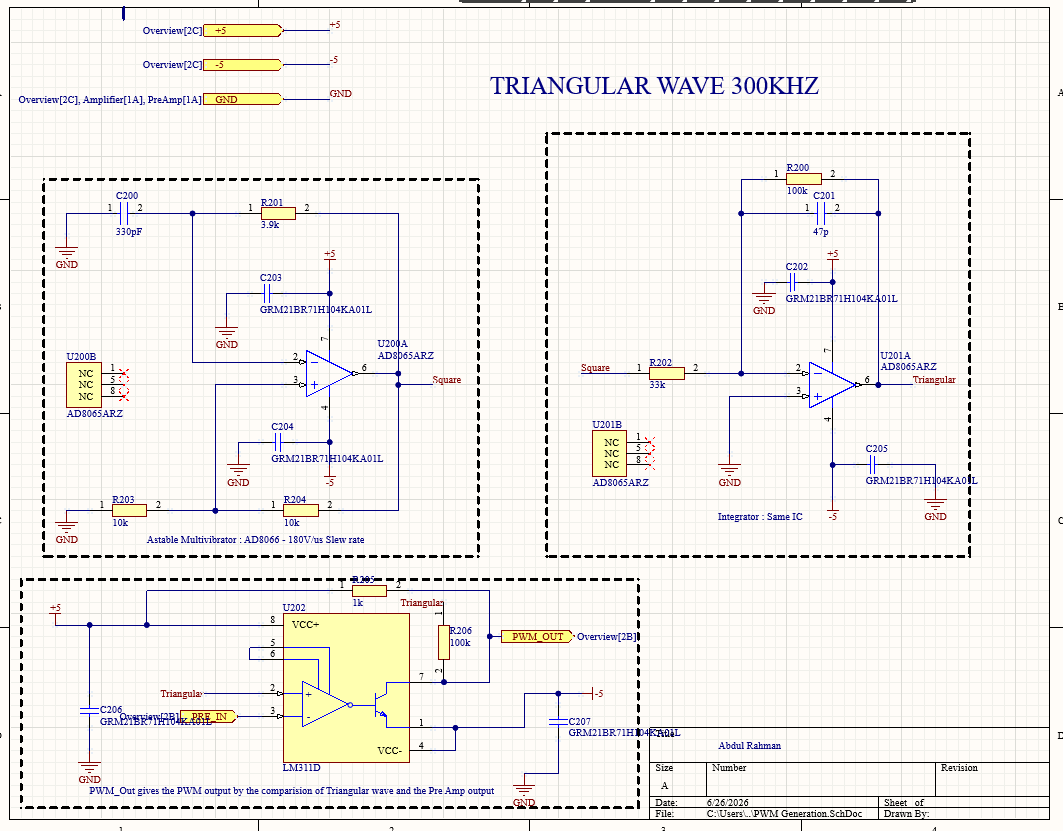
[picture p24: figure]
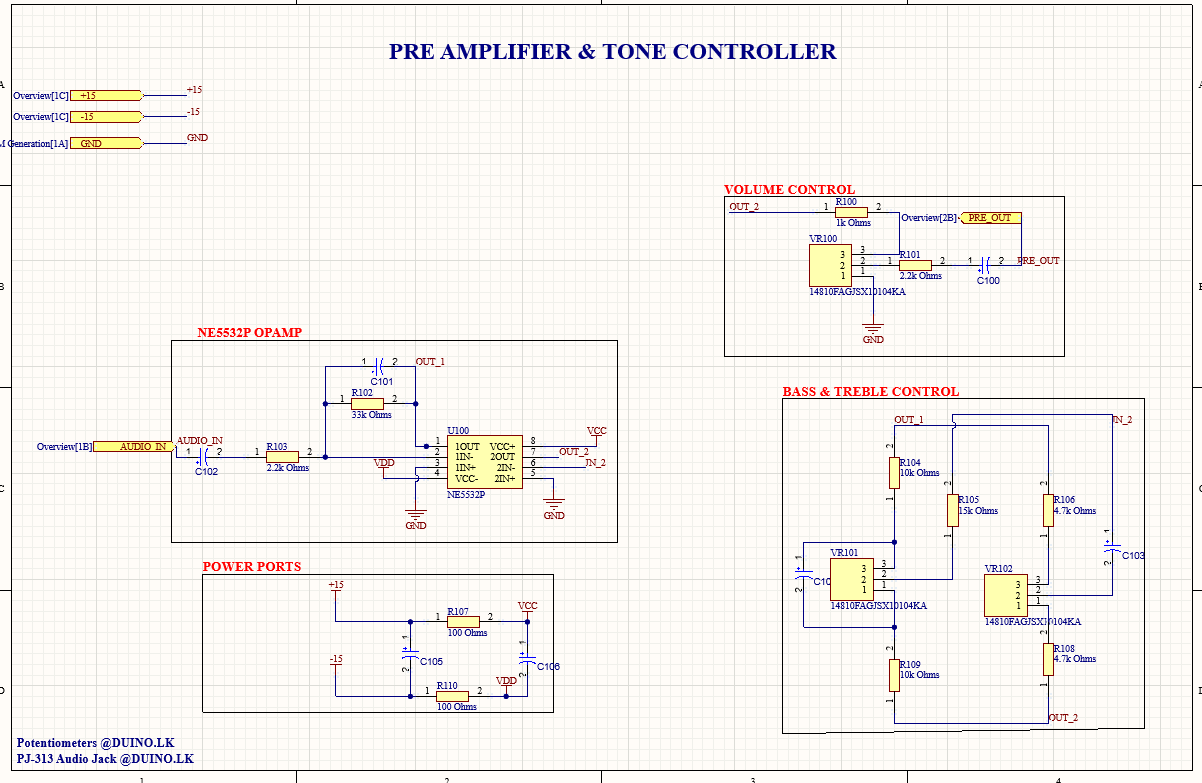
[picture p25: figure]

(a) Triangular wave & Comparator | (b) Pre amplifier

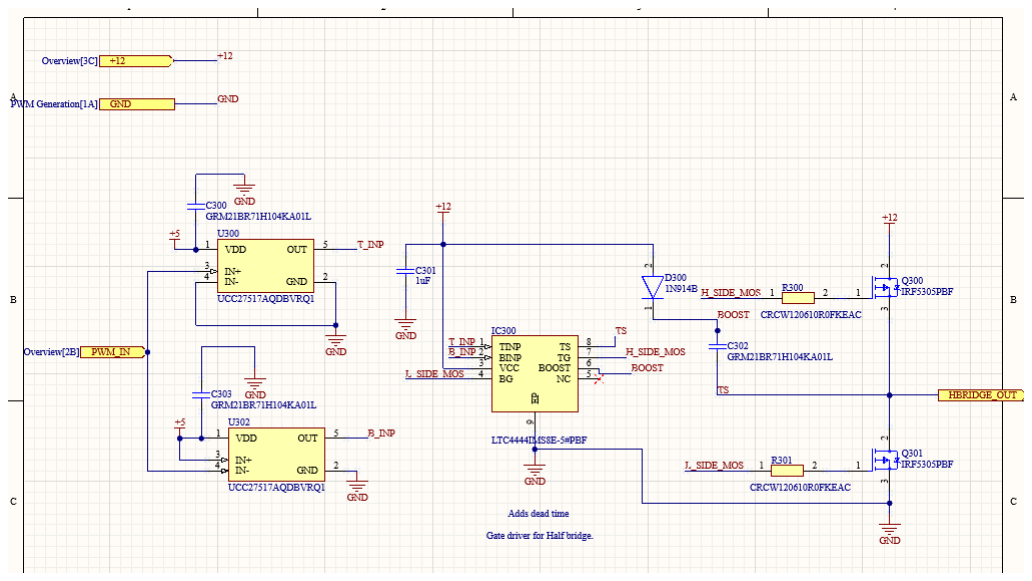
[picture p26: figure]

(c) Gate driver | (d) Filter

Figure 2.20: Simulation schematics

# Conclusion

This project successfully demonstrated the design, simulation, and implementation of a complete Class-D audio amplifier. The system was developed in stages, starting from audio pre-amplification and tone control, followed by PWM generation using a triangular carrier and comparator, and ending with a MOSFET half-bridge output stage and LC filter.

The pre-amplifier provided proper signal conditioning and improved modulation depth for PWM generation. The LM311D comparator improved switching performance compared to earlier designs. The AD8065-based triangular wave generator produced a stable high-frequency carrier suitable for PWM operation, with minor practical noise due to parasitic effects and layout limitations.

In the power stage, the IRF530 was selected for its lower gate charge, enabling better high-frequency switching performance. The IR2104 gate driver provided a reliable solution for the half-bridge, though the switching frequency had to be reduced for stable operation.

The LC output filter successfully reconstructed the audio signal, with the 4th-order Butterworth design giving better attenuation of switching noise and improved audio quality compared to lower-order filters. Simulation and experimental results showed good agreement.

Limitations included breadboard parasitics affecting high-frequency performance, reduced switching frequency compared to the original target, and the absence of PCB fabrication, which limited further optimization.

Future improvements include PCB fabrication with better layout, improved gate driver design with adaptive dead-time control, refinement of the LC filter for real speaker loads, and use of higher-efficiency switching devices such as modern MOSFETs or GaN transistors.

Overall, the project achieved a working Class-D amplifier and provided practical experience in PWM design, power electronics, and mixed-signal system integration.

# Datasheets and References

1. Texas Instruments, NE5532 Dual Low-Noise Operational Amplifier Datasheet. https://www.ti.com/lit/ds/symlink/ne5532.pdf
2. Texas Instruments, LM311 Voltage Comparator Datasheet. https://www.ti.com/lit/ds/symlink/lm311.pdf
3. Analog Devices, AD8065 High Performance FastFET Op Amp Datasheet. https://www.analog.com/media/en/technical-documentation/data-sheets/AD8065.pdf
4. Texas Instruments, NE555 Precision Timer Datasheet. https://www.ti.com/lit/ds/symlink/ne555.pdf
5. IRFZ44N N-Channel Power MOSFET, Infineon Technologies Datasheet. https://www.infineon.com/assets/row/public/documents/24/49/infineon-irfz44n-datasheet-

en.pdf (https://www.infineon.com/assets/row/public/documents/24/49/infineon-irfz44n-datasheet-en.pdf)

6. IRF530N N-Channel Power MOSFET, Infineon Technologies Datasheet. https://www.infineon.com/assets/row/public/documents/24/49/infineon-irf530n-datasheet-

en.pdf (https://www.infineon.com/assets/row/public/documents/24/49/infineon-irf530n-datasheet-en.pdf)

7. Infineon Technologies, IR2104 High and Low Side MOSFET Driver Datasheet.
IR2104 Datasheet (https://www.infineon.com/dgdl/Infineon-IR2104-DataSheet-v01_00-EN.pdf)
8. UCC27517A-Q1 Single-Channel Gate Driver, Texas Instruments Datasheet. https://www.ti.com/lit/ds/symlink/ucc27517a-q1.pdf
9. LTC4444 High Speed Synchronous N-Channel MOSFET Driver, Analog Devices Datasheet.
https://www.analog.com/media/en/technical-documentation/data-sheets/ltc4444.pdf
10. Class-D Audio Amplifier Design Basics, Texas Instruments Application Report. https://www.ti.com/lit/an/sloa119a/sloa119a.pdf
11. AN-1070: Class D Audio Amplifier Basics, Analog Devices. https://www.analog.com/media/en/technical-documentation/application-notes/AN-

1070.pdf (https://www.analog.com/media/en/technical-documentation/application-notes/AN-1070.pdf)

12. Texas Instruments, Bootstrap Circuitry Selection for Half-Bridge Configurations. Application Report (https://www.ti.com/lit/an/slua887a/slua887a.pdf)
13. Filter Design, Chris Bowick, RF Circuit Design, Reed Elsevier, ©1982.

CHAPTER 3. CONCLUSION | EN 2111 — Class D Amplifier
14. Class-D Audio Amplifier Design Basics, Texas Instruments Application Report. https://www.ti.com/lit/an/slaa701a/slaa701a.pdf

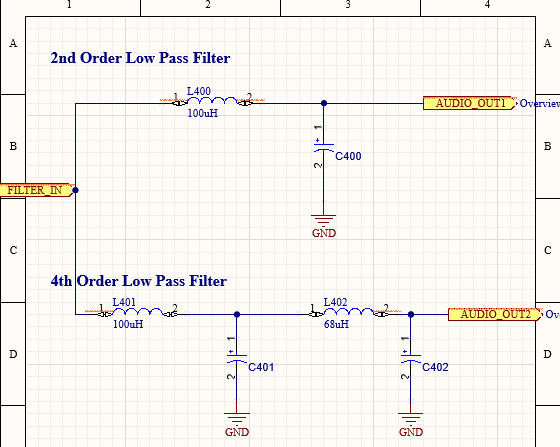
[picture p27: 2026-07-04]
Breadboard_impementation_and_Observation/filter_s.png

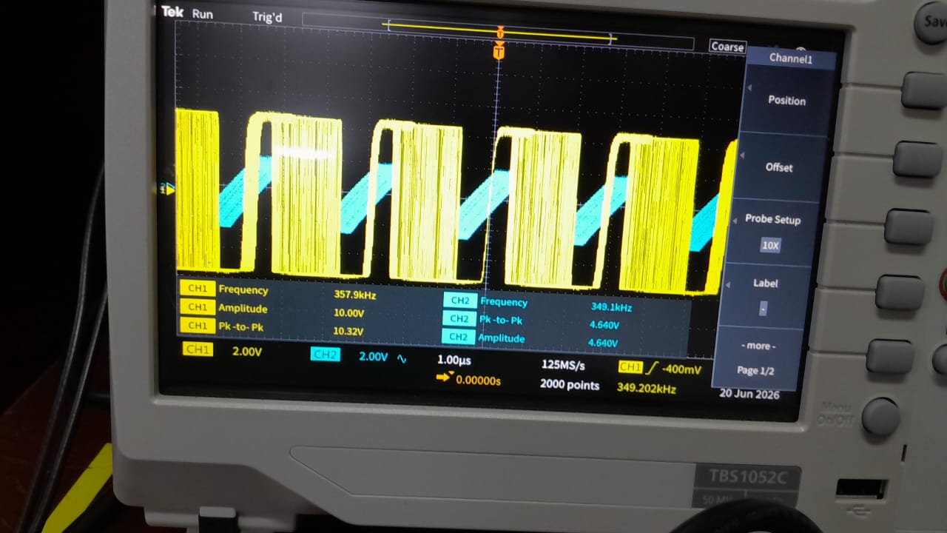
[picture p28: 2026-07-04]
Breadboard_impementation_and_Observation/Tri_vs_PWM.jpeg

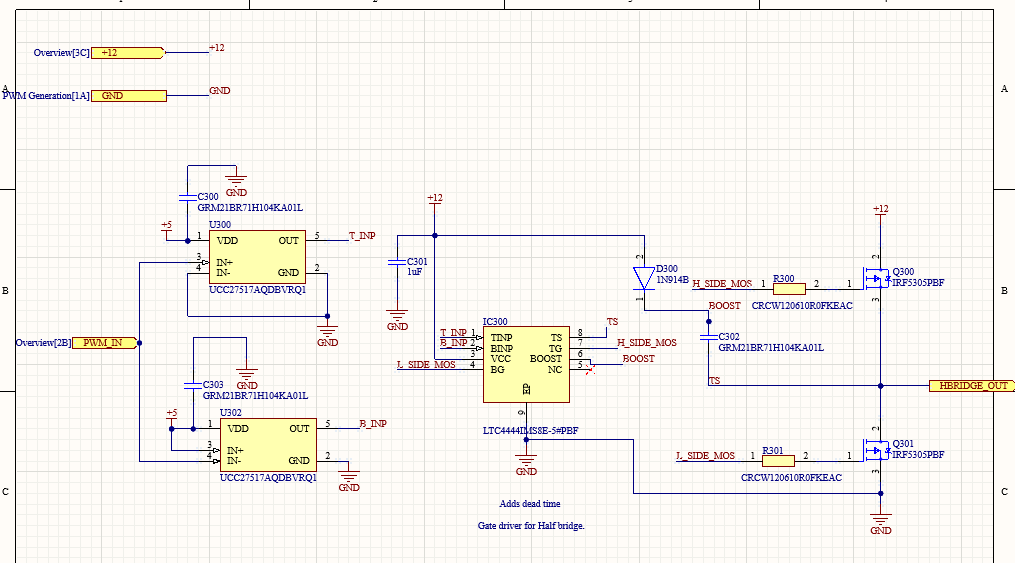
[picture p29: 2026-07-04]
Breadboard_impementation_and_Observation/driver_s.png

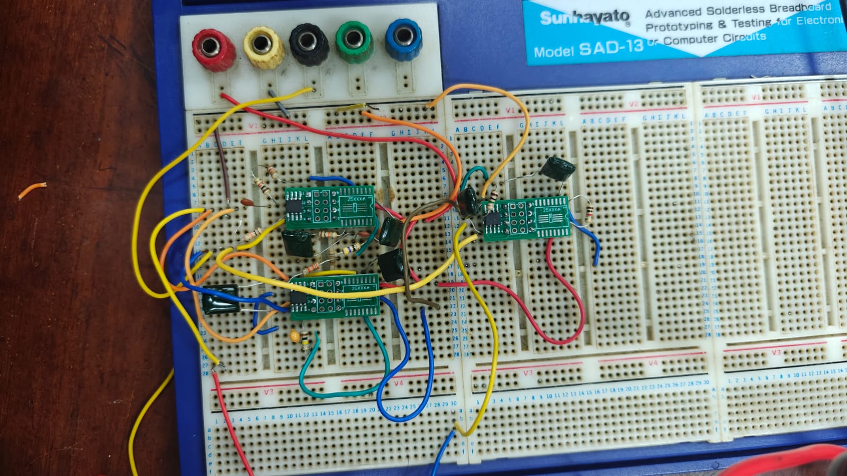
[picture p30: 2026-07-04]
Breadboard_impementation_and_Observation/tri.jpeg

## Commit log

2026-07-04 chore: organize project files into subsystem folders
    [Class_D_Amp.PrjPcb]
2026-07-04 Adding Altium schematic and PCB files
    [Amplifier.SchDoc, Class_D_Amp.PrjPcb, Filter.SchDoc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]
2026-07-04 Renamed Folders
    [Amplifier.SchDoc, Filter.SchDoc, Overview.SchDoc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]
